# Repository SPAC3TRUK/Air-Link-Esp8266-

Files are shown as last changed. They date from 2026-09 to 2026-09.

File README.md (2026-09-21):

# ⛅ Air-Link Weather Station — ESP8266 IoT Station











Progettazione e sviluppo di una stazione meteorologica IoT basata su ESP8266, ideata per il monitoraggio continuo e in tempo reale dei parametri ambientali.

Il sistema integra un'alimentazione autonoma tramite pannello solare e batteria, un'interfaccia WebApp locale avanzata, integrazione Blynk Cloud e archiviazione automatica su Google Sheets via Google Apps Script per la gestione dello storico massimo e minimo dati, diagnostica hardware sensori automatica o manuale.

---

## ✨ Caratteristiche

- 🌡️ Monitoraggio ambientale completo (Temperatura, Umidità, Pressione, CO₂/Gas, Pioggia e Luminosità)
- ⚡ Alimentazione autonoma a energia solare con gestione batteria
- 🌐 WebApp locale avanzata responsive integrata nella memoria flash (supporto Dark Mode e PWA)
- 📱 Dashboard remota tramite Blynk IoT per il controllo su smartphone
- 📊 Archiviazione storica automatica su Google Sheets tramite Google Apps Script
- ⏱️ Monitor Seriale Hardware e Log Eventi direttamente nell'interfaccia Web
- 🔍 Diagnostica Sensori e stato scheda hardware in tempo reale
- 💾 Salvataggio configurazioni permanenti su memoria LittleFS

---

## 🛠️ Componenti

- Scheda ESP8266: https://link.amazon/B07Ca3mLb
- Sensore DHT22 (Temperatura e Umidità): https://link.amazon/B07UfuIQW
- Sensore BME280 (Pressione e Temperatura): https://link.amazon/B0822Gt12
- Sensore MQ-135 (Qualità dell'aria / CO₂): https://link.amazon/B02DOjJMK
- Sensore Pioggia:  https://link.amazon/B0eubRms5
- Fotoresistore LDR (Luminosità): https://link.amazon/B0aglTqg7
- Scheda Espansione Pin: https://link.amazon/B08PETw06
- Modulo di Ricarica: https://link.amazon/B00LH5GSM
- Pannello Solare: https://link.amazon/B08UpHSUW
- Batteria: https://link.amazon/B05Mq8msb
- Pla Bianco: https://link.amazon/B065QobIY
- Pla Verde: https://link.amazon/B08JhjWYT
- Jumper: https://link.amazon/B0eURkFrb
- NFC: https://link.amazon/B0h0Xi9Gp
- Fascette termorestringenti: https://link.amazon/B01QiYgsx

---

## 🖨️ Stampa 3D

La struttura è interamente progettata in 3D ed è studiata per un assemblaggio semplice e modulare.  
Il design pulito ed essenziale protegge i componenti elettronici interni dagli agenti atmosferici, garantendo al contempo un flusso d'aria ottimale per letture accurate dei sensori di temperatura, umidità e qualità dell'aria.

- 📐 **Design ottimizzato:** Struttura a casetta con griglia e inclinazione per proteggere i sensori dall'irraggiamento diretto.
- 🧩 **Assemblaggio** Colla a caldo o Silicone per proteggere al meglio l'hardware.
- ☀️ **Resistenza outdoor:** Progettata per essere stampata in materiali resistenti ai raggi UV e alle intemperie (es. PETG o TPU).

---

## ☀️Alimentazione Autonoma

La stazione è progettata per operare in ambienti remoti o outdoor. L'energia viene fornita da un pannello solare che carica la batteria integrata, garantendo continuità di servizio anche durante la notte o nelle giornate di scarsa insolazione. Si può connettere un unità esterna quando il sole è assente.

---

## 🌐 Web App

L’ESP8266 ospita una WebApp responsive integrata accessibile da qualsiasi browser digitando l'indirizzo IP della stazione.

L'interfaccia comprende:

- 📊 Dashboard: Indicatori visivi ad anello, stato del meteo e valori min/max.
- 💻 Log e Eventi: Monitor seriale dal vivo e registro degli eventi di sistema.
- 📈 Database: Integrazione in tempo reale del foglio Google Sheets interno.
- 🛠️ Hardware Monitor: Diagnostica sensori, RAM libera, velocità Flash e segnale Wi-Fi (RSSI)
  
Non serve alcuna app aggiuntiva: è persino installabile come PWA (Progressive Web App) direttamente sullo schermo del tuo telefono!

---

## 📊 Google Sheets & Apps Script

I dati acquisiti dai sensori vengono inviati ad intervalli regolari a un foglio Google Sheets dedicato utilizzando un Webhook e un script Google Apps Script. Questo consente di mantenere uno storico delle misurazioni minime e massime della giornata in modo gratuito, illimitato e sempre consultabile.

---

## 📁 Struttura del progetto:

AirLinkWeatherStation/
│
├── File_3D_Case/
├── File_3D_Case/(file .stl della struttura)
├── File_3D_Case/(file .stl del supporto)
│
├── Interfaccia_Web_Airlink/
├── Interfaccia_Web_Airlink/index.html
│
├── Progettazione_e_Documentazione/
├── Progettazione_e_Documentazione/SchemaElettrico.png
├── Progettazione_e_Documentazione/Progetto_Gui_Air-Link
├── Progettazione_e_Documentazione/1.png
├── Progettazione_e_Documentazione/(eventuali altre immagini)
│
├── src/
├── src/Air_link/
├── src/Air_link/Air_link.ino
├── src/Air-Link_ApScriptGoogle/
├── src/Air-Link_ApScriptGoogle/Code.js
│
├── LICENSE
└── README.md

---

## 🚀 Installazione

1. Scarica o clona il repository. 
2. Configura lo script Google Apps Script all'interno del tuo account Google ed estrai l'URL di distribuzione. 
3. Inserisci le tue credenziali Wi-Fi, la chiave Blynk e l'URL di Google Script all'interno del file firmware e nella WebApp.
4. Carica l'interfaccia HTML/JS nella memoria flash dell'ESP8266 usando il plugin LittleFS.
5. Compila e carica il codice sull'ESP8266.
6. Apri l'indirizzo IP assegnato alla stazione dal tuo browser o l'app BlynkIot per iniziare il monitoraggio!

---

## 🎥 Immagini e Video

- Linkedin Post: https://www.linkedin.com/posts/christianmosci_iot-esp8266-embeddedsystems-activity-7507849930984697856-ldRu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
  
---

## 📸 Foto

<p align="center">
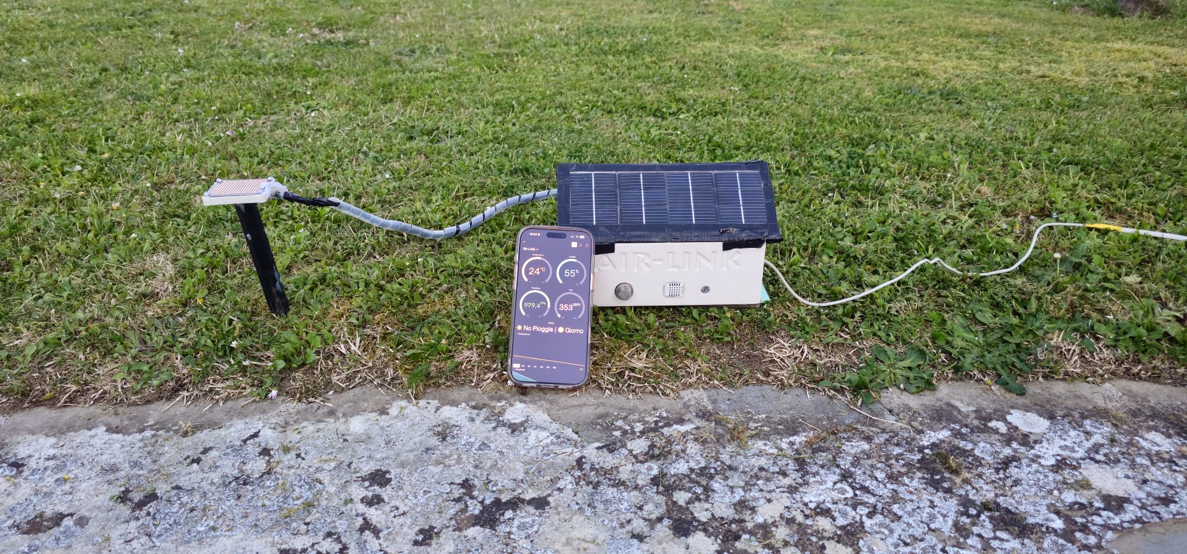
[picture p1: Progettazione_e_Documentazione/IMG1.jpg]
  
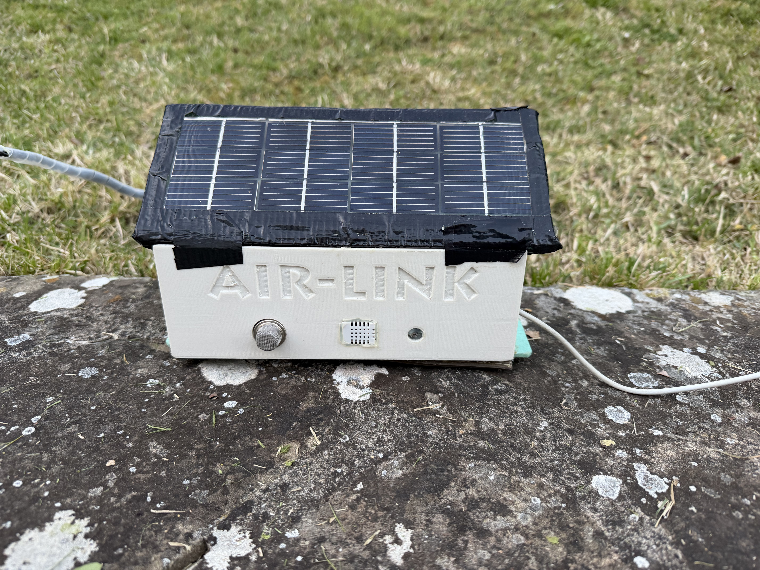
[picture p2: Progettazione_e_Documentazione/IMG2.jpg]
  
</p>

<p align="center">
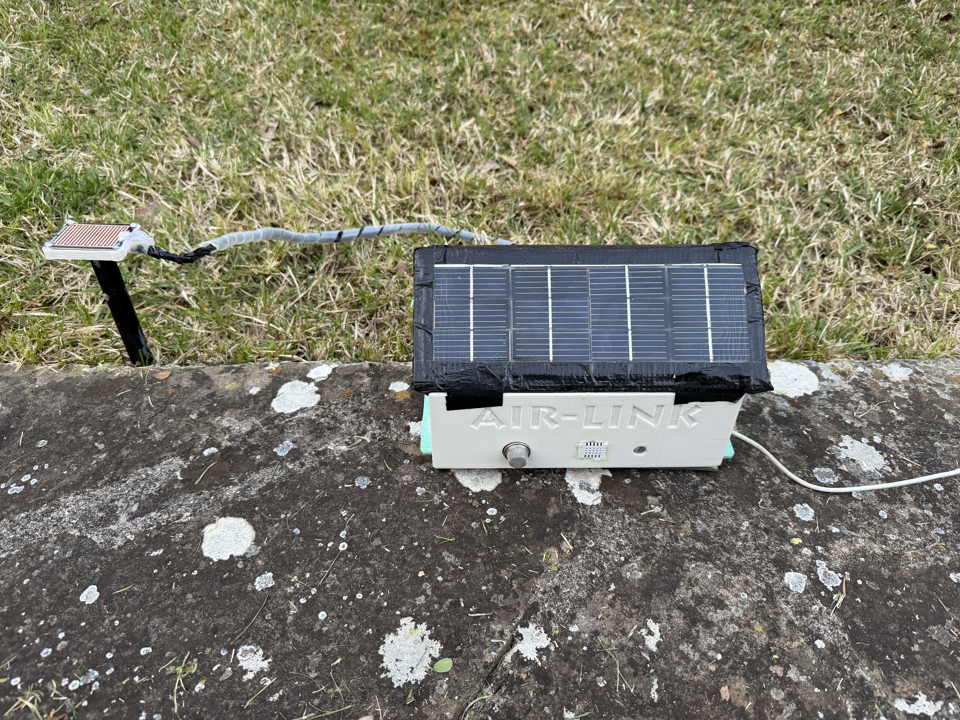
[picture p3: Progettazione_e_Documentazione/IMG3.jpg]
  
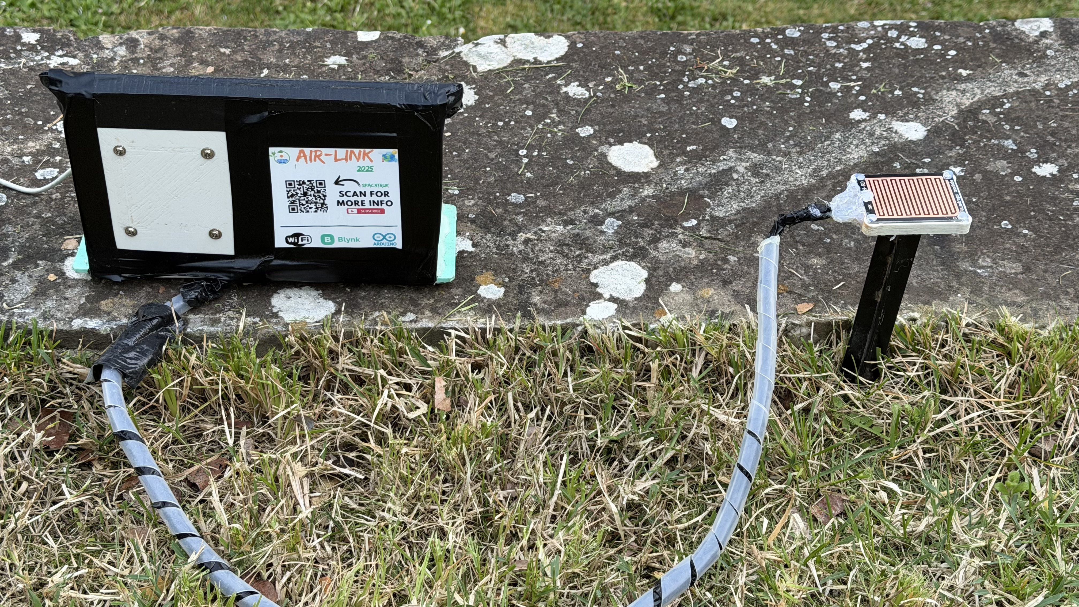
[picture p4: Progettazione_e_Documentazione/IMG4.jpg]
  
</p>

<p align="center">
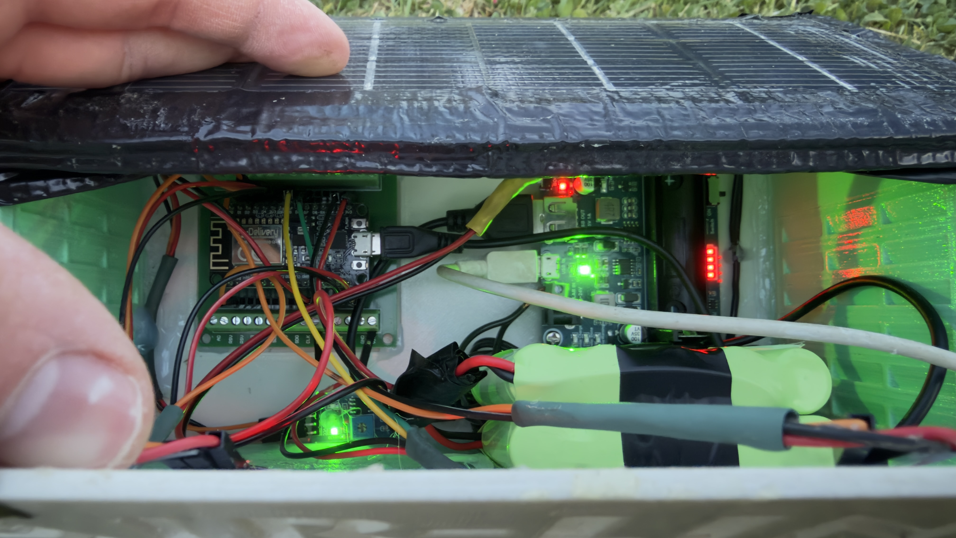
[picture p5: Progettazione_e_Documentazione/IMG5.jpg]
  
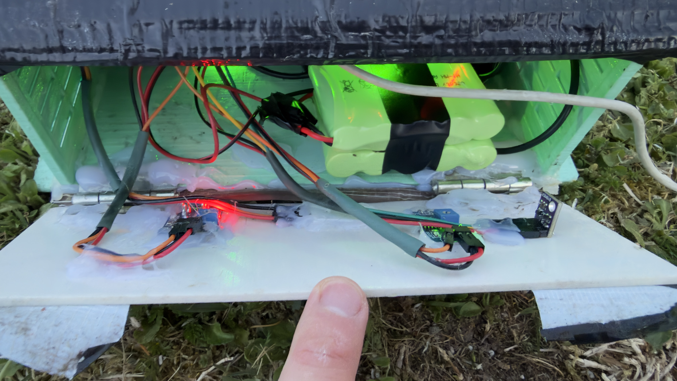
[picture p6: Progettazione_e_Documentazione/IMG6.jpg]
  
</p>

<p align="center">
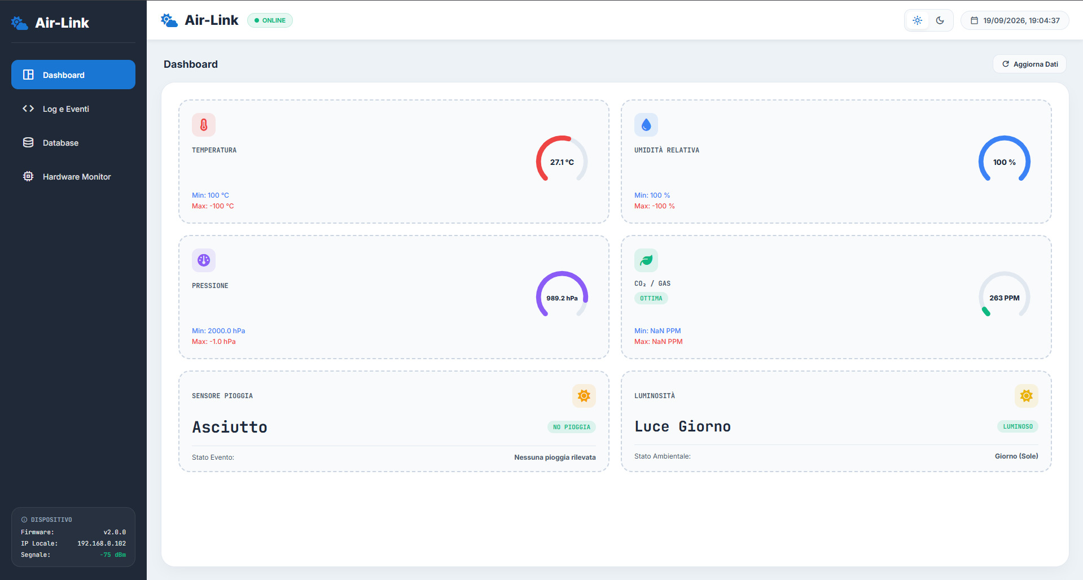
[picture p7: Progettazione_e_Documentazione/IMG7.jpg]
  
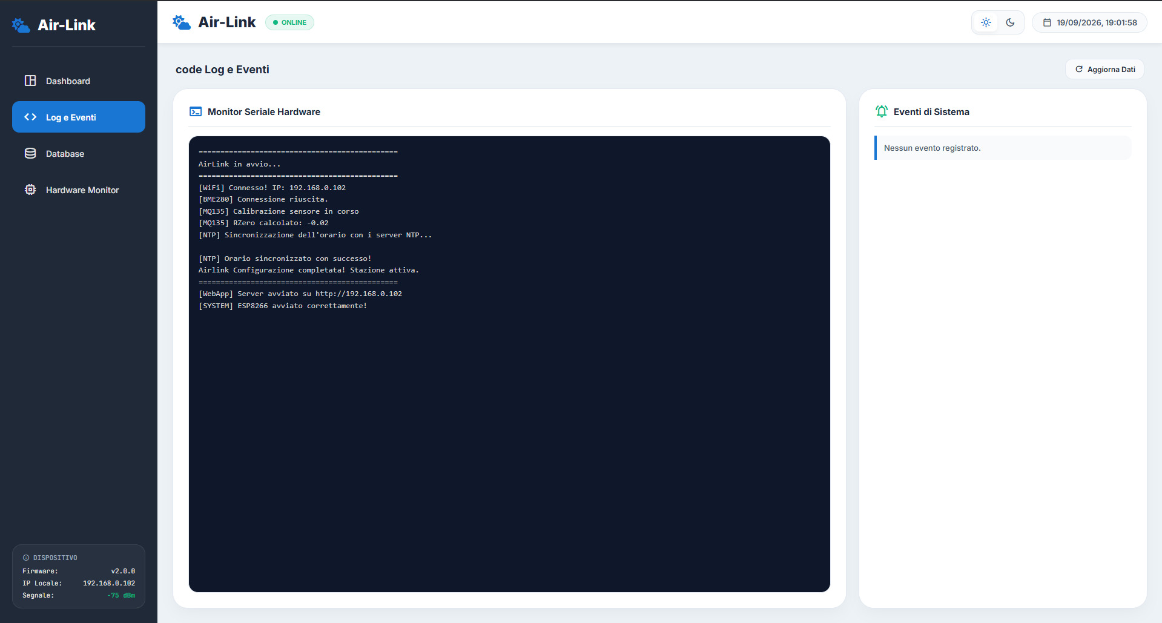
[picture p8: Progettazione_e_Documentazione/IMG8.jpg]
  
</p>

<p align="center">
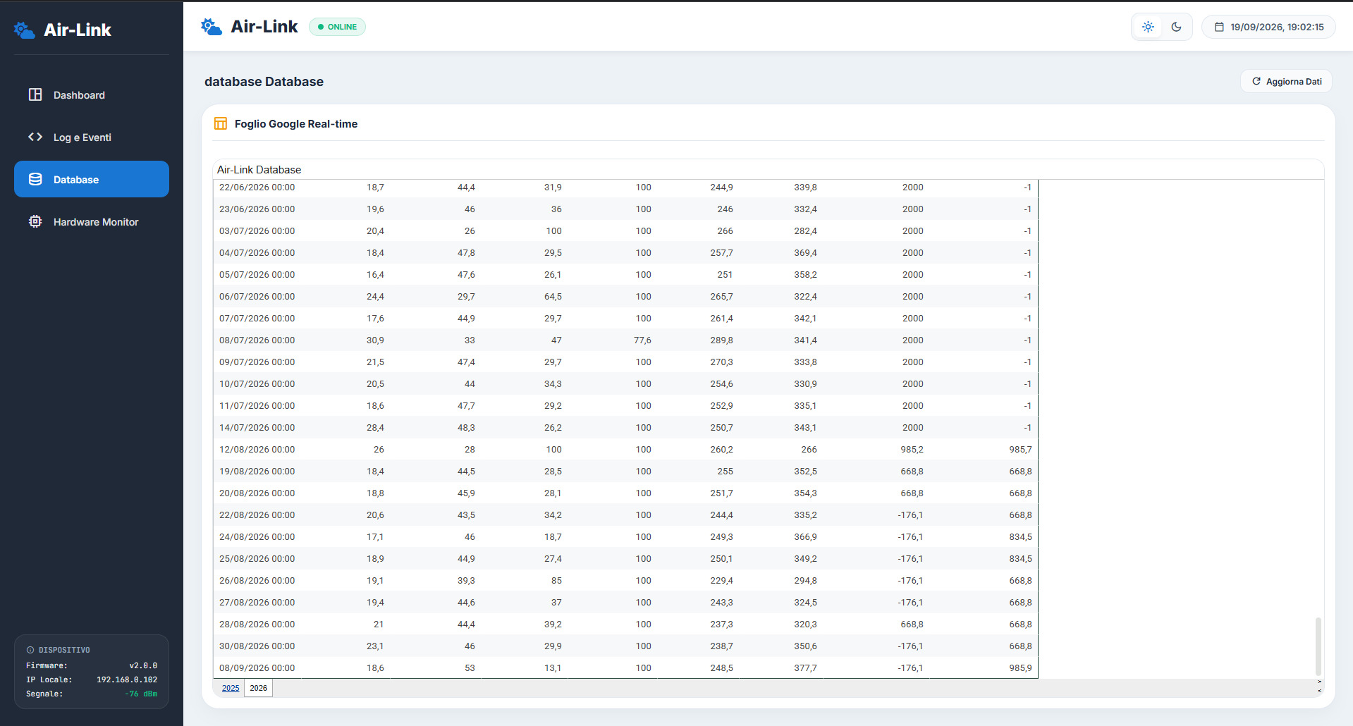
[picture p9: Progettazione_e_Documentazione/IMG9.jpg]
  
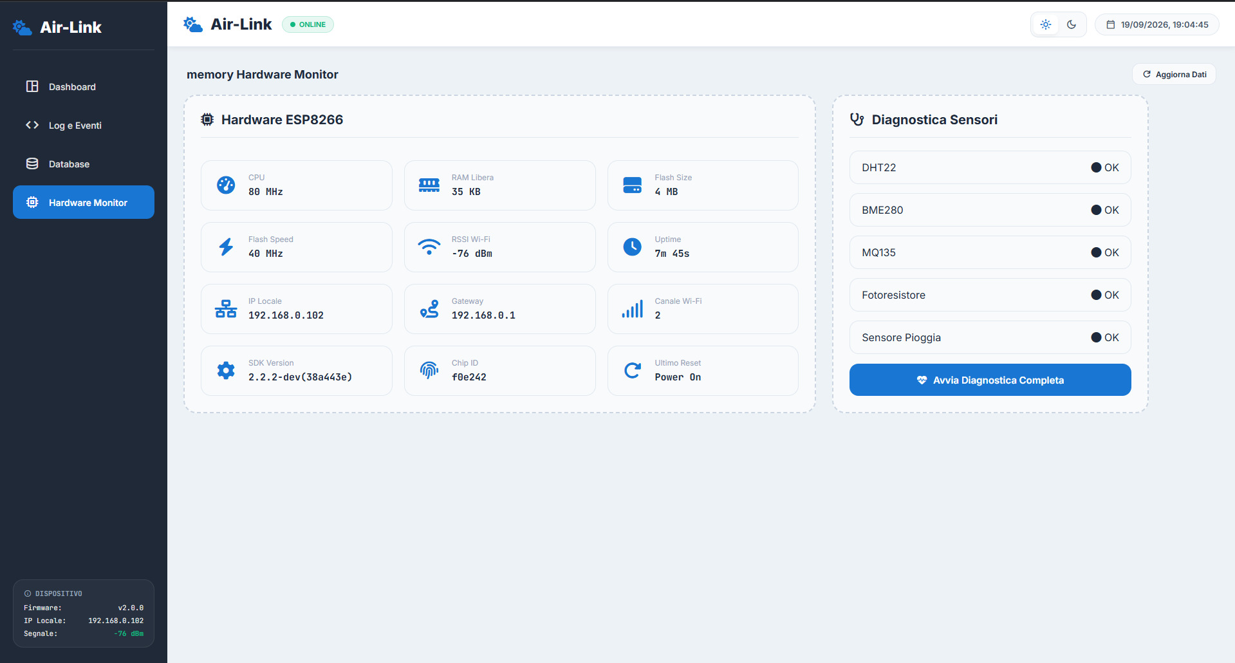
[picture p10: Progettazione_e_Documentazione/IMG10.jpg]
  
</p>

---

## 🔐 Licenza

Questo progetto è distribuito sotto licenza:

### **Creative Commons Attribution‑NonCommercial 4.0 International (CC BY‑NC 4.0)**  


Puoi:

- Condividere  
- Modificare  
- Creare progetti derivati  

Ma **non puoi usarlo per scopi commerciali**.

Testo completo della licenza:  
https://creativecommons.org/licenses/by-nc/4.0/

---

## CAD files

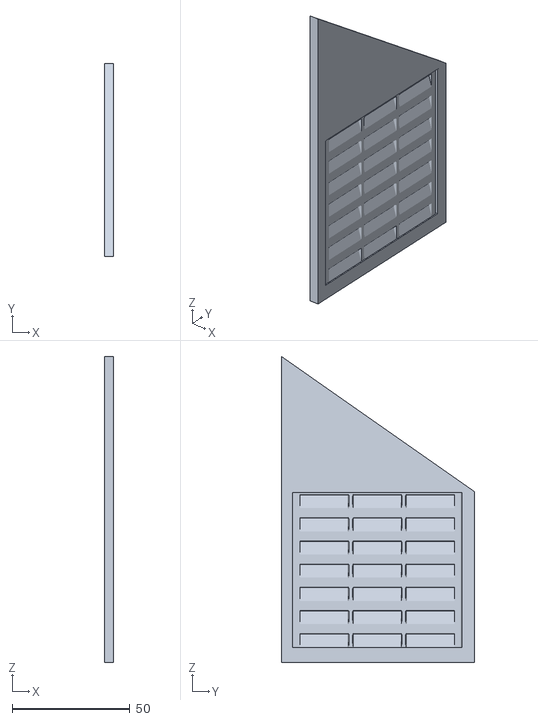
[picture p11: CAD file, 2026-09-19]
FIle_3D_Case/Supporto Laterale Progetto Air-Link sx.stl
4.00 x 82.0 x 130.0

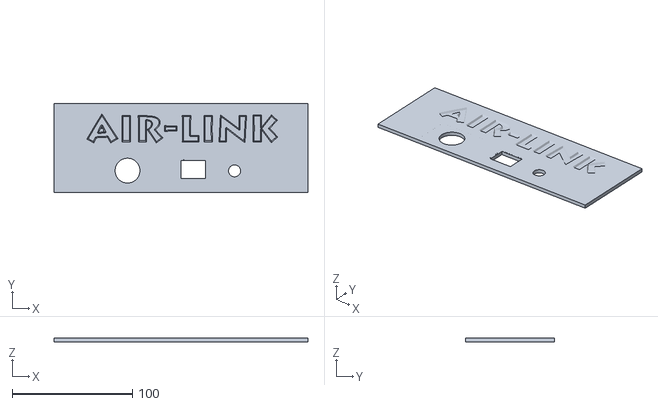
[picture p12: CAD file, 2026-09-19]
FIle_3D_Case/Parete Davanti Progetto Air-Link.stl
211.0 x 74.0 x 3.00

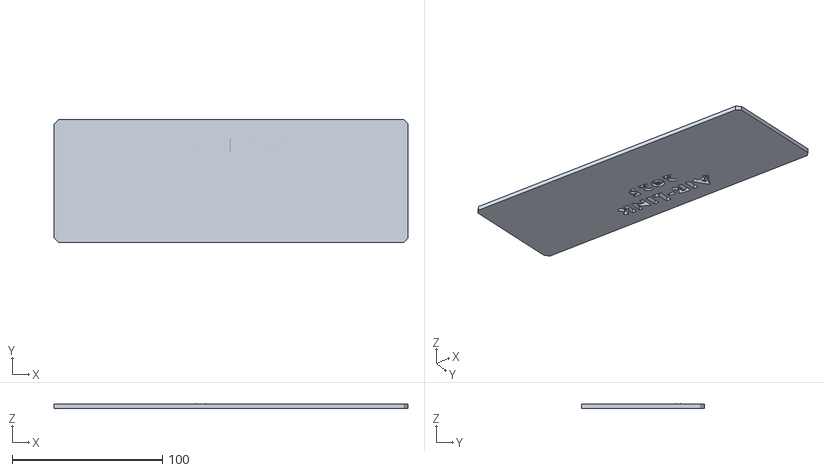
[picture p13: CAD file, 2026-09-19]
FIle_3D_Case/Pavimento Progetto Air-Link.stl
236.0 x 82.0 x 3.60

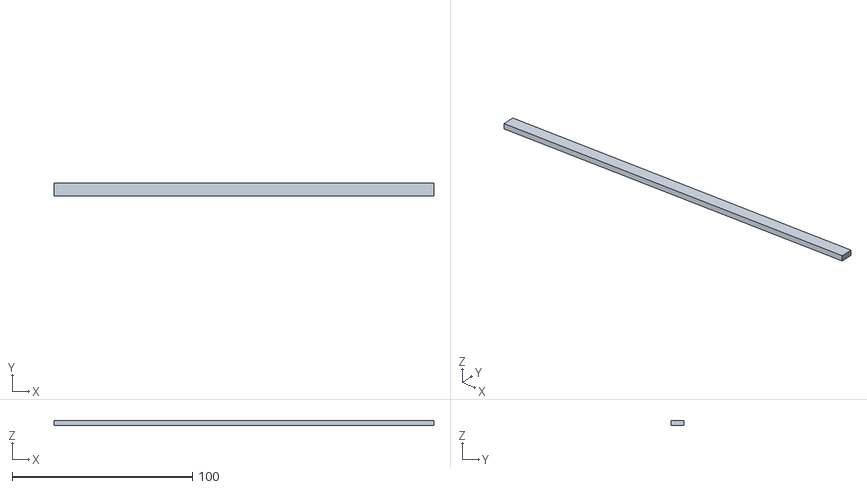
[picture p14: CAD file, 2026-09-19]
FIle_3D_Case/barra copri tetto progetto Air-Link.stl
211.0 x 7.00 x 3.00

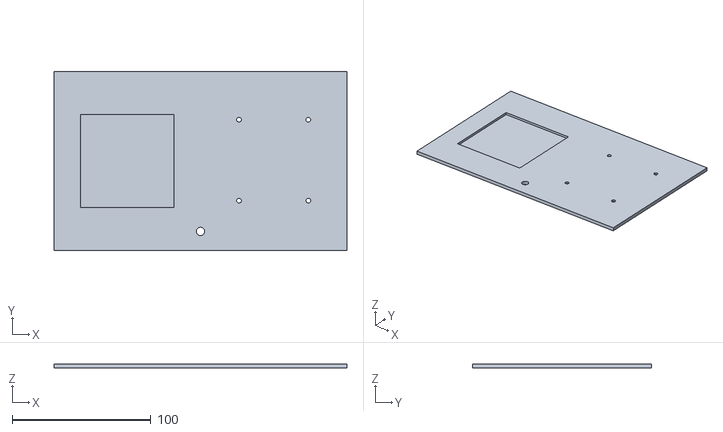
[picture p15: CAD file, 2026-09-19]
FIle_3D_Case/Parete Dietro Progetto Air-Link.stl
211.0 x 129.0 x 3.00

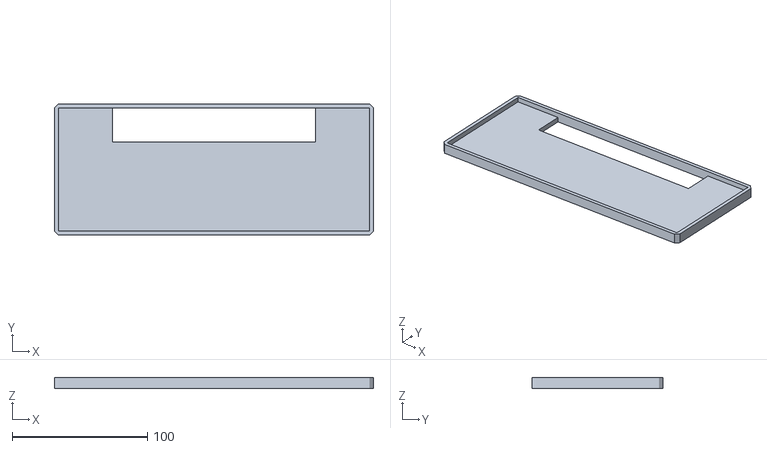
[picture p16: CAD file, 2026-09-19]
FIle_3D_Case/Tetto Progetto Air-Link.stl
236.0 x 97.0 x 8.00

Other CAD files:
FIle_3D_Case/Supporto Laterale Progetto Air-Link dx.stl

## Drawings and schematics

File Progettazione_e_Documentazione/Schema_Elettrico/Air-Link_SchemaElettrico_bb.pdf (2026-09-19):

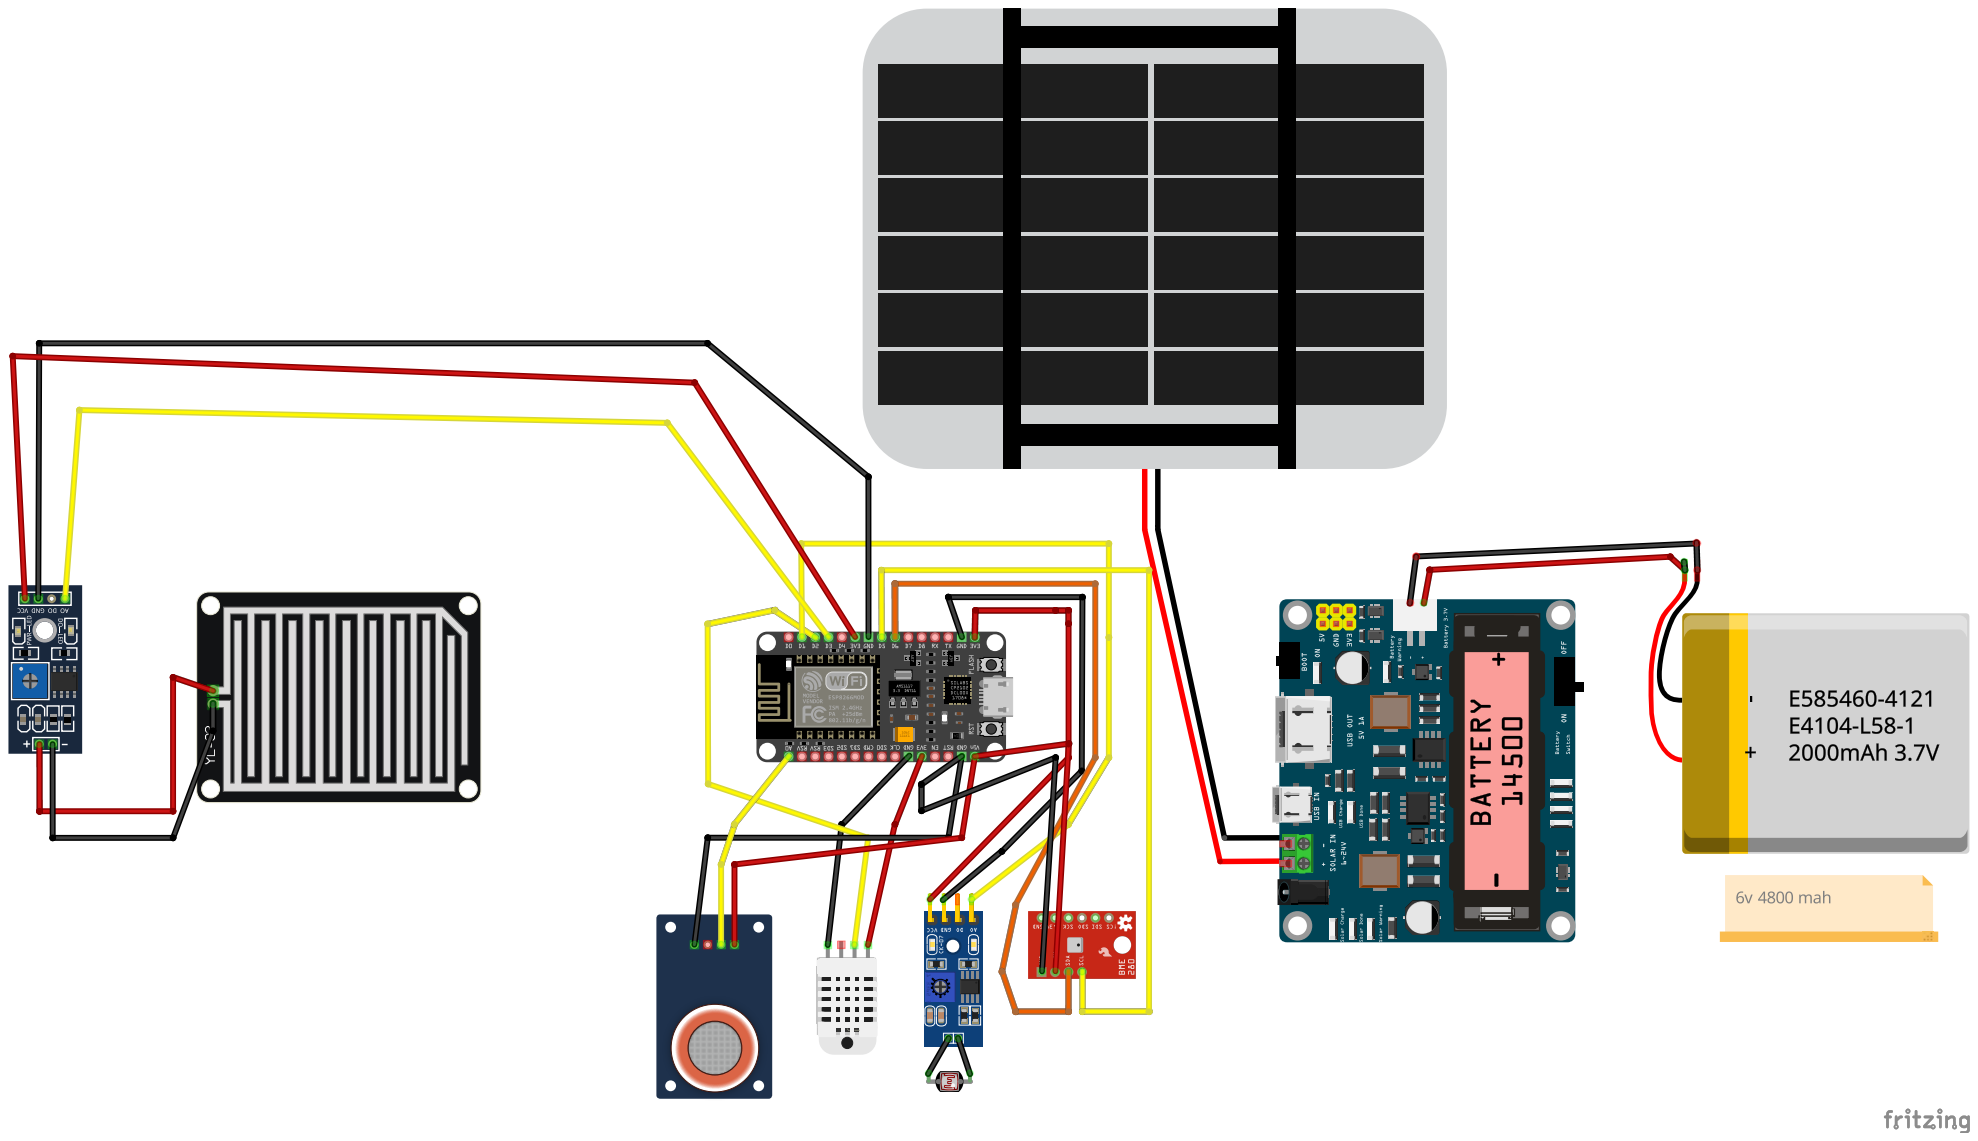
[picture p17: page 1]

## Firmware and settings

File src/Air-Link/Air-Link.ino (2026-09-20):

/*
 * =========================================================================
 *                  STAZIONE METEOROLOGICA AIR-LINK (ESP8266)
 * =========================================================================
 * 
 * Descrizione:
 * Stazione meteo IoT basata su ESP8266. Esegue il monitoraggio in tempo reale 
 * con sensori (DHT22, BME280, MQ135, Raindrop Module, Fotoresistore), trasmette le 
 * letture all'app Blynk IoT ogni 30 minuti, esegue una diagnostica pianificata 
 * dello stato dei sensori due volte al giorno, e a mezzanotte invia i dati 
 * minimi e massimi registrati a Google Sheets tramite Google Apps Script.
 * Possibilità di visualizzare i dati anche su una webapp locale
 * 
 * Struttura dei File del Progetto:
 * - Airlink.ino         : Punto di ingresso principale, Setup e Loop.
 * - config.h            : Configurazione di Blynk, WiFi,Google, Pin e Variabili Globali.
 * - sensors_manager.h   : Logica di lettura, elaborazione e invio dei sensori.
 * - diagnostics.h       : Gestione della diagnostica dei sensori oraria.
 * - google_sheets.h     : Logica di invio dei record min/max a Google Sheets.
 * - WebApp.h            : Logica e codice Webapp locale + EndPoint + Handler
 * - HardwareInfo.h      : Logica e EndPoint per recuperare dati del hardware del microcontrollore
 * - web_serial.h        : Logica e EndPoint per recuperare dati dal monitor seriale e mandarli alla webapp
 * - 1.png.h             : Array in bite per l'icona della webapp in png
 * Autore: Christian Mosci - SPAC3TRUK - christian_mosci
 * =========================================================================
 */

// 1. CONFIGURAZIONE E SERIALE WEB 
#include "config.h"
#include "web_serial.h"
#include "diagnostics.h"

// 2. GESTORE SENSORI
#include "sensors_manager.h"

// 3. GOOGLE SHEETS E WEB APP 
#include "google_sheets.h"
#include "1.png.h"
#include "WebApp.h"
#include "HardwareInfo.h"


// Crea l'istanza del server sulla porta 80
ESP8266WebServer server(80);

void setup() {
  Serial.begin(9600);
  delay(1500);
  logWebSerial("==============================================");
  logWebSerial("AirLink in avvio... ");
  logWebSerial("==============================================");

  // Inizializzazione della connessione Blynk IoT e WiFi
  Blynk.begin(auth, ssid, pass);

  // Stampa l'IP locale sul Monitor Seriale e digitale su webApp
  Serial.print("[WiFi] Connesso! Indirizzo IP: ");
  Serial.println(WiFi.localIP());
  logWebSerial("[WiFi] Connesso! IP: " + WiFi.localIP().toString());

  // Inizializzazione dei moduli Hardware / Sensori
  dht.begin();                      // DHT22 (Temperatura & Umidità)
  Wire.begin(BME_SDA, BME_SCL);     // BME280 (SDA=Pin D6, SCL=Pin D5)
  
  if (!bme.begin(0x76)) {
    logWebSerial("[BME280] Sensore BME280 non trovato");
  } else {
    logWebSerial("[BME280] Connessione riuscita.");
  }

  pinMode(RAIN_SENSOR, INPUT);      // Pin digitale sensore pioggia
  pinMode(FOTORESISTORE, INPUT);    // Pin digitale fotoresistore
  
  //Calibrazione iniziale sensore gas MQ135
  logWebSerial("[MQ135] Calibrazione sensore in corso");
  delay(5000);
  float rzero = gasSensor.getRZero();
  logWebSerial("[MQ135] RZero calcolato: " + String(rzero));
  
  // Re-inizializza il sensore con la corretta resistenza base di calibrazione (RZero)
  gasSensor = MQ135(MQ135_PIN, rzero);

  // Configurazione orario di sistema tramite protocollo NTP con timeout anti-crash
  configTime("CET-1CEST,M3.5.0,M10.5.0/3", "pool.ntp.org", "time.nist.gov");
  logWebSerial(F("[NTP] Sincronizzazione dell'orario con i server NTP..."));
  
  int timeoutNTP = 0;
  while (!time(nullptr) && timeoutNTP < 20) { // Max 10 secondi di attesa
    delay(500);
    logWebSerial(F("."));
    yield(); // Previene il reset del Watchdog
    timeoutNTP++;
  }

  if (time(nullptr)) {
    logWebSerial(F("\n[NTP] Orario sincronizzato con successo!"));
  } else {
    logWebSerial(F("\n[NTP] Timeout: Sincronizzazione fallita, il sistema proseguirà comunque."));
  }

  // Configurazione dei timer schedulati con BlynkTimer
  timer.setInterval(1800000L, ManagerSensori);           // Legge e invia i dati a Blynk ogni 30 MINUTI
  timer.setInterval(60000L, checkMezzanotte);         // Verifica se inviare i dati riepilogativi a mezzanotte (ogni 1 min)
  timer.setInterval(60000L, checkDiagnosticaOraria);  // Esegue la diagnostica pianificata alle 09:00 e 21:00 (ogni 1 min)

  logWebSerial("Airlink Configurazione completata! Stazione attiva.");
  logWebSerial("==============================================");

// Rotta Favicon classica da PROGMEM
server.on("/favicon.png", HTTP_GET, []() {
  server.send_P(200, "image/png", (const char*)__1_png, sizeof(__1_png));
});

//Rotta per l'icona PWA da PROGMEM
server.on("/icon-192.png", HTTP_GET, []() {
  server.send_P(200, "image/png", (const char*)__1_png, sizeof(__1_png));
});

//Rotta per il manifest.json
server.on("/manifest.json", HTTP_GET, handleManifest);

// Rotta Service Worker
server.on("/sw.js", HTTP_GET, []() {
  server.send_P(200, "application/javascript", "self.addEventListener('fetch', function(e) {});");
});


  initWebApp(); // Avvia le rotte della web app

  // Registra le rotte API
  server.on("/api/serial", HTTP_GET, handleApiSerial);
  server.on("/api/events", HTTP_GET, handleApiEvents);

  server.begin(); // Avvia il Web Server DOPO la registrazione di tutte le rotte

  logWebSerial("[SYSTEM] ESP8266 avviato correttamente!");
}


void loop() {
  Blynk.run(); // Mantiene attiva la comunicazione bidirezionale con Blynk Cloud
  timer.run(); // Gestisce ed esegue i compiti schedulati dai timer
  server.handleClient(); // Gestisce le richieste web in background
  // Rilascia la CPU al sistema operativo per evitare il crash del Watchdog
  yield();
}

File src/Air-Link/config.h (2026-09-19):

#ifndef CONFIG_H
#define CONFIG_H

#include <Arduino.h>


// CONFIGURAZIONE BLYNK E WEB SERVER
// Inserisci qui le tue credenziali Blynk IoT
#define BLYNK_TEMPLATE_ID " " // Specifica il tuo Template ID di Blynk
#define BLYNK_TEMPLATE_NAME " " // Specifica il tuo Template Name di Blynk
#define BLYNK_PRINT Serial

#include <ESP8266WiFi.h>
#include <BlynkSimpleEsp8266.h>

#include <ESP8266WebServer.h>

// Istanza globale del server HTTP sulla porta 80
extern ESP8266WebServer server;

// LIBRERIE SENSORI
#include <DHT.h>
#include <DHT_U.h>
#include <Wire.h>
#include <Adafruit_Sensor.h>
#include <Adafruit_BME280.h>
#include <MQ135.h>

//LIBRERIE SETUP GOOGLE SHEETS 
#include <WiFiClientSecure.h>
#include <ESP8266HTTPClient.h>

//LIBRERIE GESTIONE ORARIO
#include <time.h>
#include <TZ.h>

// CREDENZIALI WIFI E AUTH BLYNK 

char auth[] = " ";// Inserisci le tue credenziali blynk personali
char ssid[] = " ";// Inserisci il tuo ssid wifi
char pass[] = ""; // Inserisci la tua password wifi

// PIN DI COLLEGAMENTO SENSORI
#define DHTPIN 4                 // Pin D2 su ESP8266 per DHT22
#define DHTTYPE DHT22   
#define BME_SDA 12               // Pin D6 su ESP8266 per BME280 SDA
#define BME_SCL 14               // Pin D5 su ESP8266 per BME280 SCL
#define FOTORESISTORE 5          // Pin D1 su ESP8266 per Fotoresistore
#define RAIN_SENSOR 0            // Pin D3 su ESP8266 per Sensore Pioggia
#define MQ135_PIN A0             // Pin A0 su ESP8266 per MQ135

#define SEALEVELPRESSURE_HPA (1013.25)  // Valore standard pressione livello mare

//DICHIARAZIONE ISTANZE GLOBALI SENSORI
DHT dht(DHTPIN, DHTTYPE);
Adafruit_BME280 bme;
MQ135 gasSensor = MQ135(MQ135_PIN);
BlynkTimer timer;

// CONFIGURAZIONE GOOGLE APP SCRIPT

const char* scriptURL = " "; // URL fornito da Google Apps Script dopo il deploy come Web App

//VARIABILI GLOBALI PER MASSIME E MINIME GIORNALIERE
float tempMin = 100.0;
float tempMax = -100.0;
float umidMin = 100.0;
float umidMax = -100.0;
float co2Min = 10000.0;
float co2Max = -1.0;
float pressioneMin = 2000.0;
float pressioneMax = -1.0;

//FLAG DI CONTROLLO STATO GIORNALIERO
bool inviatoOggi = false;
bool diagnosticaMattina = false;
bool diagnosticaSera = false;

#endif // CONFIG_H

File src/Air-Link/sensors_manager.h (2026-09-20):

#ifndef SENSORS_MANAGER_H
#define SENSORS_MANAGER_H

#include "diagnostics.h"
#include "config.h"
#include "web_serial.h"

RisultatoDiagnostica eseguiControlloSensori();

// LETTURA SENSORE DHT22
void Dht22() {
  float temperatura = dht.readTemperature();
  float umidita = dht.readHumidity();

  // Verifica validità letture e aggiorna i record minimi e massimi giornalieri
  if (!isnan(temperatura)) {
    if (temperatura < tempMin) tempMin = temperatura;
    if (temperatura > tempMax) tempMax = temperatura;
    Blynk.virtualWrite(V0, temperatura); // Invio a Blynk Virtual Pin V0
  } else {
    logWebSerial("❌ Errore nella lettura della temperatura da DHT22");
  }

  if (!isnan(umidita)) {
    if (umidita < umidMin) umidMin = umidita;
    if (umidita > umidMax) umidMax = umidita;
    Blynk.virtualWrite(V1, umidita);     // Invio a Blynk Virtual Pin V1
  } else {
    logWebSerial("❌ Errore nella lettura dell'umidità da DHT22");
  }
}

// LETTURA SENSORE BME280
void Bme280() {
  float pressione = bme.readPressure() / 100.0F; // hPa

  if (!isnan(pressione) && pressione > 0) {
    if (pressione < pressioneMin) pressioneMin = pressione;
    if (pressione > pressioneMax) pressioneMax = pressione;
    Blynk.virtualWrite(V2, pressione);   // Invio a Blynk Virtual Pin V2
  } else {
    logWebSerial("❌ Errore nella lettura della pressione da BME280");
  }
}

// GESTIONE PIOGGIA E FOTORESISTORE
inline void MeteoLable() {
  String meteo;
  meteo.reserve(32); // Pre-alloca la memoria per evitare frammentazione

  // 1. Lettura Pioggia su pin D3 (LOW = Pioggia)
  bool haPiovuto = (digitalRead(RAIN_SENSOR) == LOW);

  // 2. Lettura Fotoresistore su pin D1 (LOW = Giorno)
  bool eGiorno = (digitalRead(FOTORESISTORE) == LOW); 

  // 3. Costruzione stringa per Blynk
  meteo = haPiovuto ? "🌧 Pioggia" : "☀ No Pioggia";
  meteo += " | ";
  meteo += eGiorno ? "🌞 Giorno" : "🌙 Notte";

  // Invio a Blynk Virtual Pin V4
  Blynk.virtualWrite(V4, meteo);
}

// LETTURA SENSORE QUALITÀ DELL'ARIA MQ135
void SensoreMQ135() {
  float temperatura = dht.readTemperature();
  float umidita = dht.readHumidity();

  // Se i valori DHT22 non sono validi, usiamo valori di default per la calibrazione
  if (isnan(temperatura) || isnan(umidita)) {
    temperatura = 20.0;
    umidita = 50.0;
  }

  float correctedPPM = gasSensor.getCorrectedPPM(temperatura, umidita);

  if (!isnan(correctedPPM) && correctedPPM >= 0) {
    if (correctedPPM < co2Min) co2Min = correctedPPM;
    if (correctedPPM > co2Max) co2Max = correctedPPM;
    Blynk.virtualWrite(V6, correctedPPM); // Invio a Blynk Virtual Pin V6
  } else {
    logWebSerial("❌ Errore nella lettura o calcolo PPM da MQ135");
  }
}

// MANAGER COORDINATORE DEI SENSORI
void ManagerSensori() {
  logWebSerial("Avvio lettura ciclica e aggiornamento Blynk Cloud...");

  // Esegue le letture ordinate e pulite inviando i dati ai Virtual Pin corretti
  Dht22();
  Bme280();
  MeteoLable();
  SensoreMQ135();

  // Notifica l'avvenuto invio a Blynk nel Seriale Web
  logWebSerial("[BLYNK] Pacchetto dati meteo inviato con successo!");
}

#endif // SENSORS_MANAGER_H

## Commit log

2026-09-19 Progetto Air-Link
    -Progetto Air-Link Completo di Codice, Codice AppScript, Modelli3D, Schema Elettrico, Progettazione Gui, WebApp, Immagini e Icona.
    [Air-Link_SchemaElettrico.fzz, Parete Davanti Progetto Air-Link.stl, Parete Dietro Progetto Air-Link.stl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]
2026-09-20 Risoluzione Problemi Blynk e Google Sheets
    -Risoluzione Problema invio dati pioggia e stato giorno e notte a blynk iot
    -Risoluzione Problema invio dati a Google Sheets per minimo e massimo.
    [Air-Link.ino, sensors_manager.h]

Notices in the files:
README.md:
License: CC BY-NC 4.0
